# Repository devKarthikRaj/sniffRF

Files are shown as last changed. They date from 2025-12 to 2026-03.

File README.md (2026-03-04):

# sniffRF

## Project Snapshot
| Spec | Details |
|---|---|
| MCU | STM32L053R8 (M0+) |
| Firmware | Written in C++ via STM32CubeIDE |
| RF Detector | AD8318 Logarithmic (RF Power) Detector |
| Frequency Range | 902-928 MHz |
| Measurement Method | RF power -> Analog Voltage -> STM32 ADC |
| Power System | Li-ion battery with BQ24074 power path manager (charger included) |
| Display | OLED (SSD1306) |
| PCB | 4-layer mixed signal PCB designed in KiCad |
| Manufacturing | PCB fabrication and assembly done by JLCPCB |
| Cost | S$250 |
| Status | Hardware bring-up completed, core functionality validated (excluding OLED) |

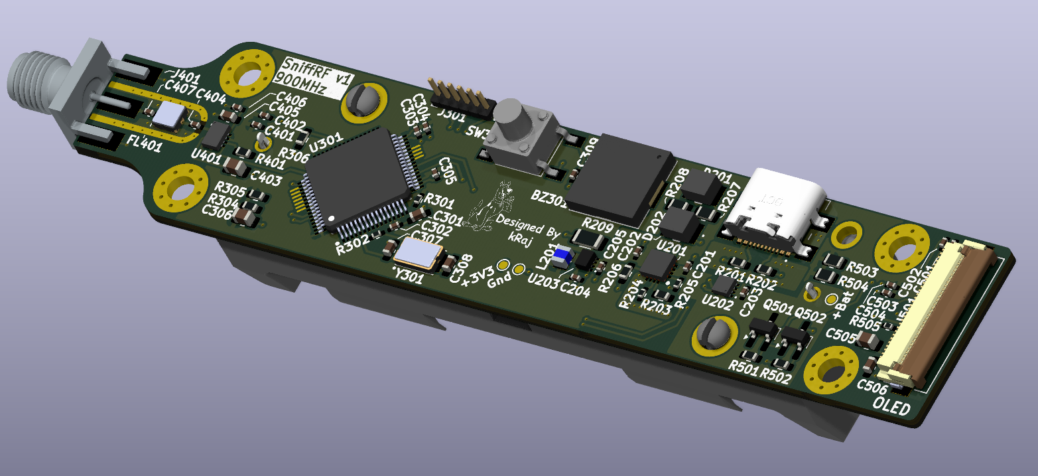
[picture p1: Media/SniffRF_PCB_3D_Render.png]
PCB 3D Render
 <br>
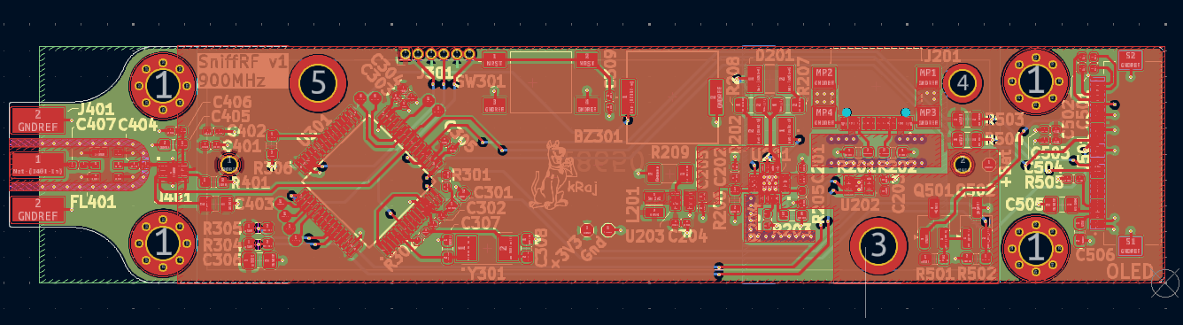
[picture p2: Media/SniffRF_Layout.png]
SniffRF Layout
 <br>
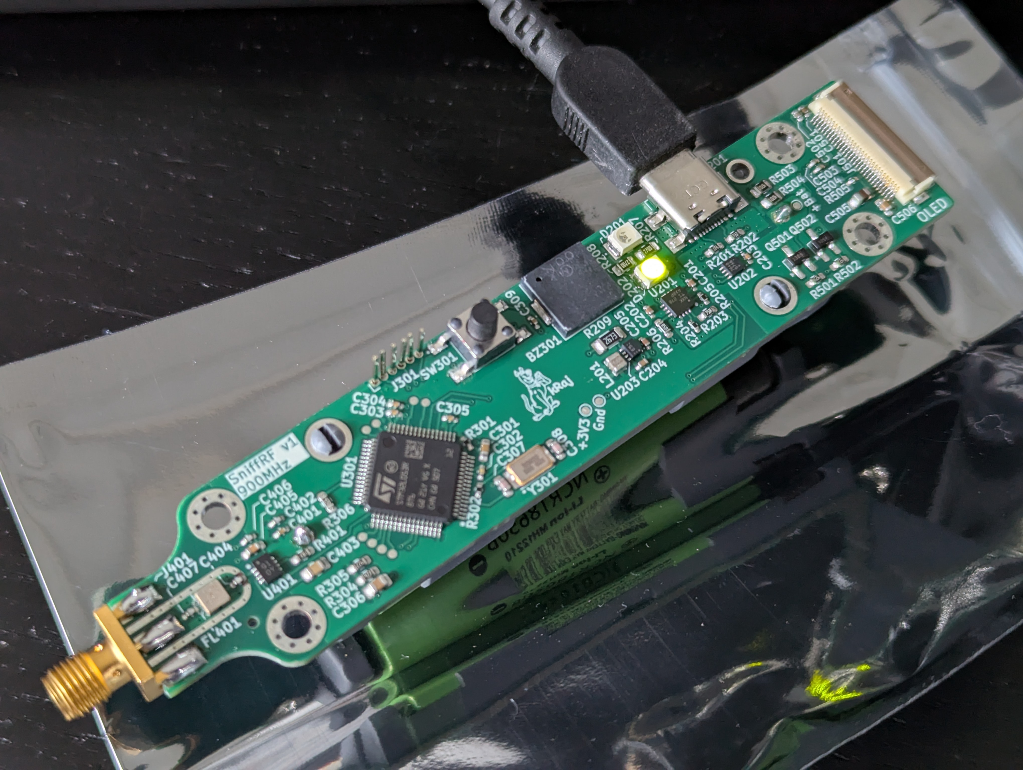
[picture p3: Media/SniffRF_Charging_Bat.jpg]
SniffRF Charging Battery
 <br>
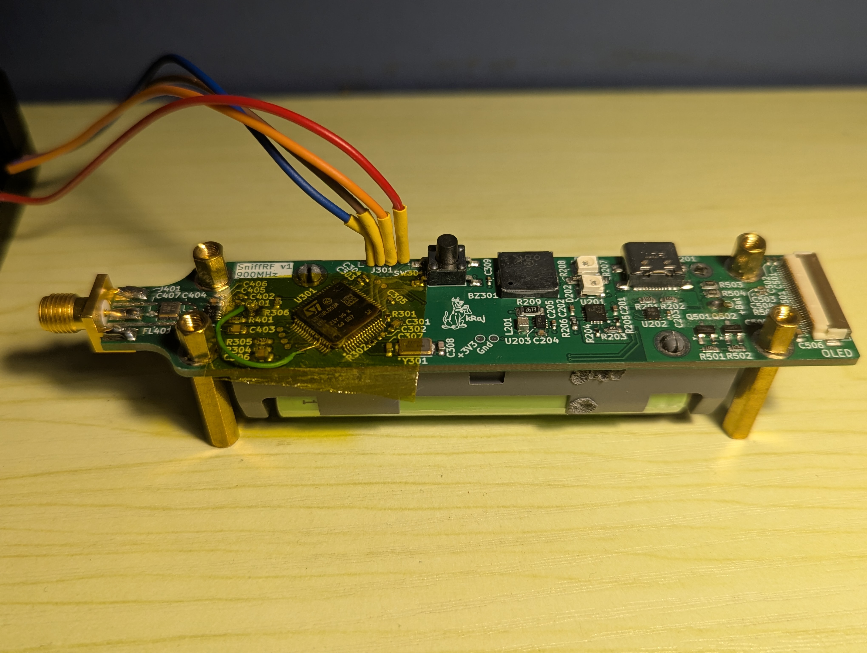
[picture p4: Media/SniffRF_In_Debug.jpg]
SniffRF In Debug
 <br>

## About
SniffRF is a simple RSSI detector aka a signal strength detector for the 902MHz to 928MHz band using an AD8318 logarithmic detector chip and built around an STM32L053R8 MCU. SniffRF displays the RSSI level on a mini OLED. SniffRF will also pulse a buzzer with varying frequency based on the RSSI level. <br>

## Sub-Systems
* RF: Input from SMA fed into AD8318 log detector. <br>
* MCU: STM32L053R8 M0+ interface circuitry, program/debug MCU via SWD.
* UI: OLED for visual feedback and buzzer for audio feedback.
* Power: 1x 18650 cell with BQ24074 power path manager, charge via USB-C, MAX1704 fuel gauge, simple buck converter for 3.3V

## Application
* SniffRF could be used to track RF transmitters using their radio signature. <br>
* SniffRF could also be used to gauge the noise floor at a particular location to select or deploy a receiver at said location. <br>   

*Note: As of now, SniffRF only tunes into the 902-928MHz band.*

## Bring-Up and Validation
* **STM32 MCU able to boot up and connect via J-Link debugger to STM32CubeIDE.** STM32 UART connection working as expected. <br>
* **AD8318 RSSI detection circuit is fully functional from about -60dBm to 0dBm. A known RF source (Sine wave transmitted at 915MHz from an Adalm Pluto SDR) was moved toward and away from the SniffRF PCB - this caused the RSSI readings to increase and decrease as expected.** <br>
* Li-Ion battery power path manager is able to charge the 18650 battery when a USB-C charge cable is plugged in. MAX1704 fuel gauge is able to read Li-Ion battery voltage + capacity and send this data over to the STM32 for display over UART. <br>
* Buzzer interfaced to STM32 is functional. <br>
* Unable to verify OLED functionality due to lack of assembled SniffRF boards, TBC... <br>

## Thoughts...
This is my first STM32 PCB! I made this PCB to learn STM32 design as well as try my hand at mixed signal PCB design. Feels good to finally strike this off my bucket list. Spent a few weekends working on this project over 3 months. More advanced RF PCBs to come!

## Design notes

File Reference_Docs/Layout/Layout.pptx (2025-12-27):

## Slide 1

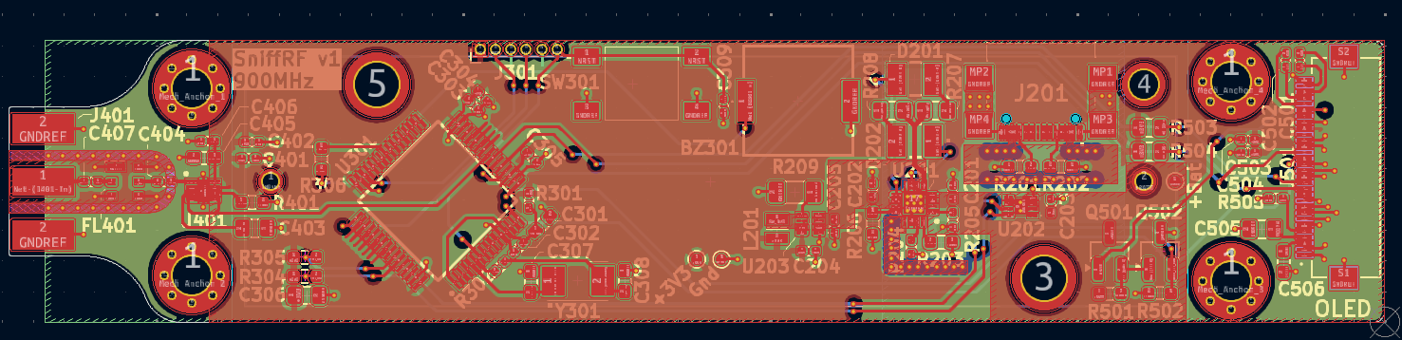
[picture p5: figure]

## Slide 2

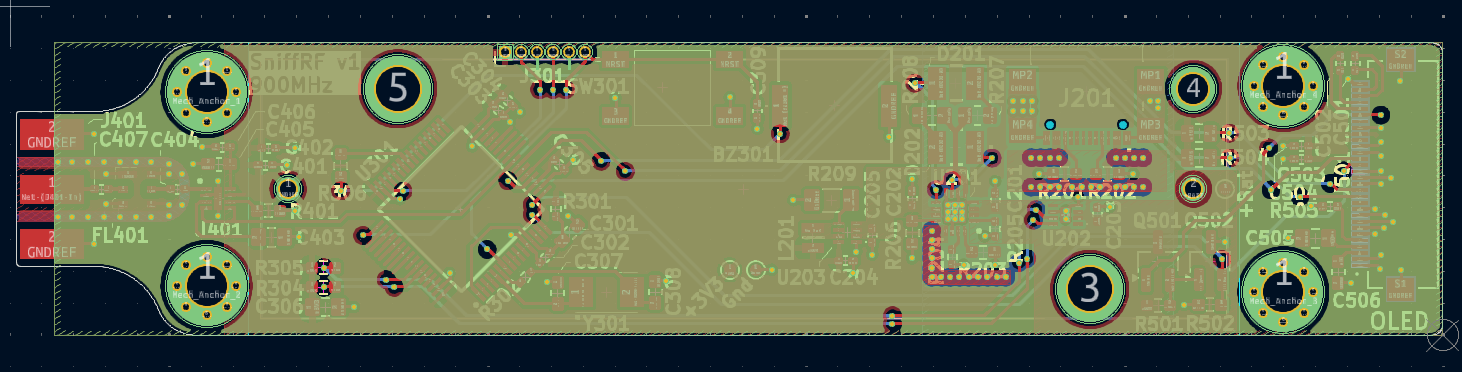
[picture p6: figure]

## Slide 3

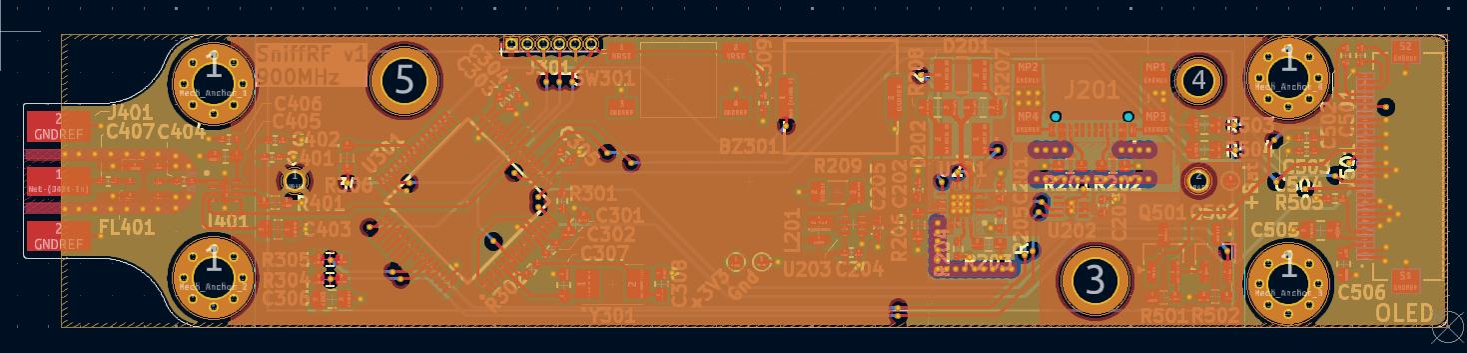
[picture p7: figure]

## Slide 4

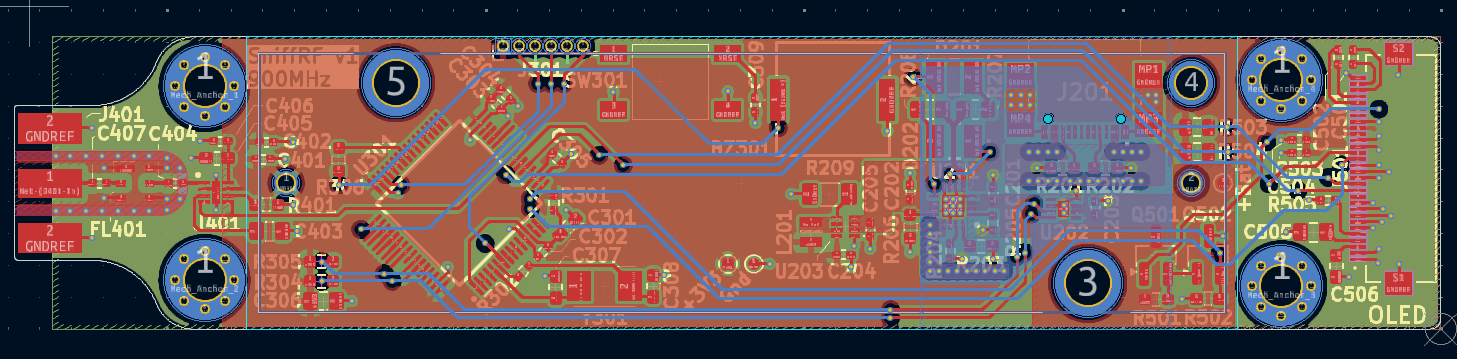
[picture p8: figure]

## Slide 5

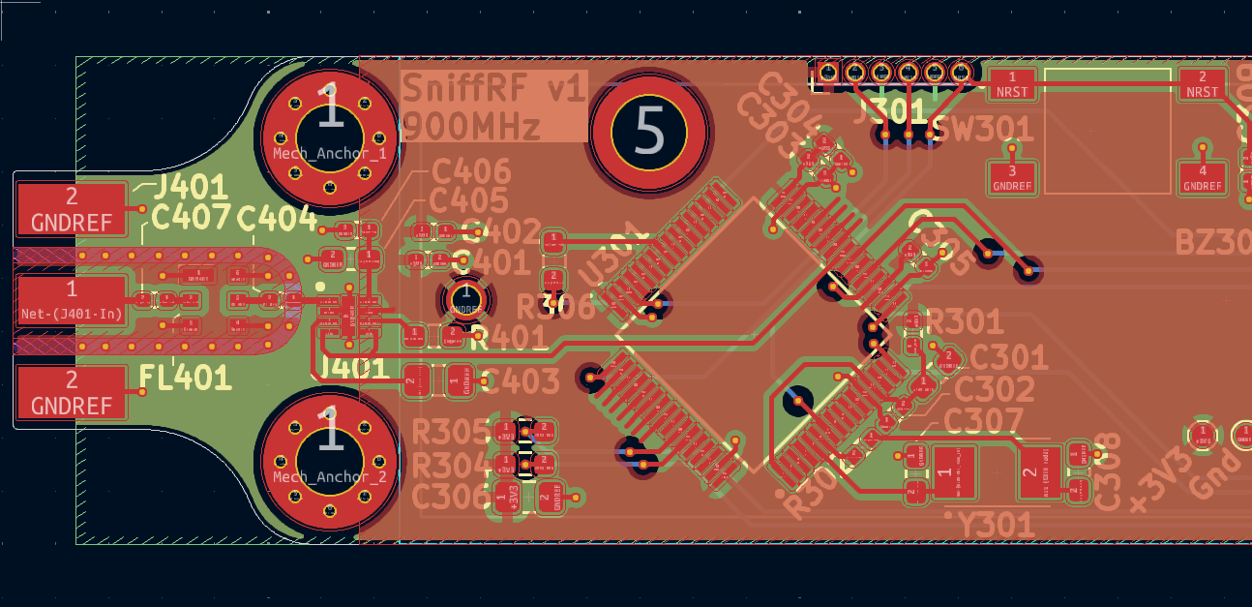
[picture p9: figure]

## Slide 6

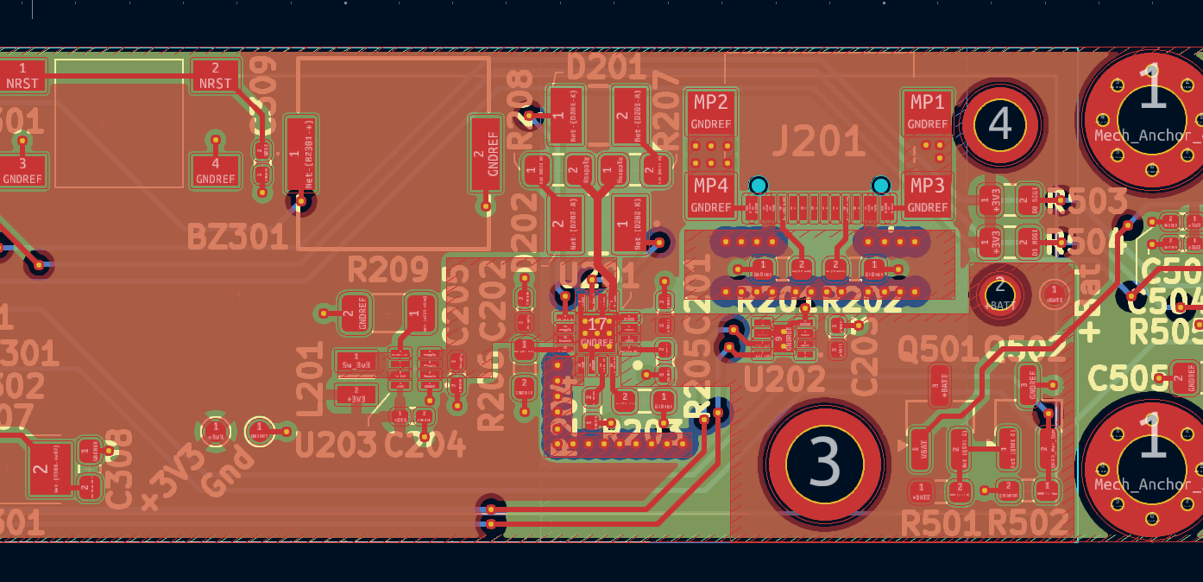
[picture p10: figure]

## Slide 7

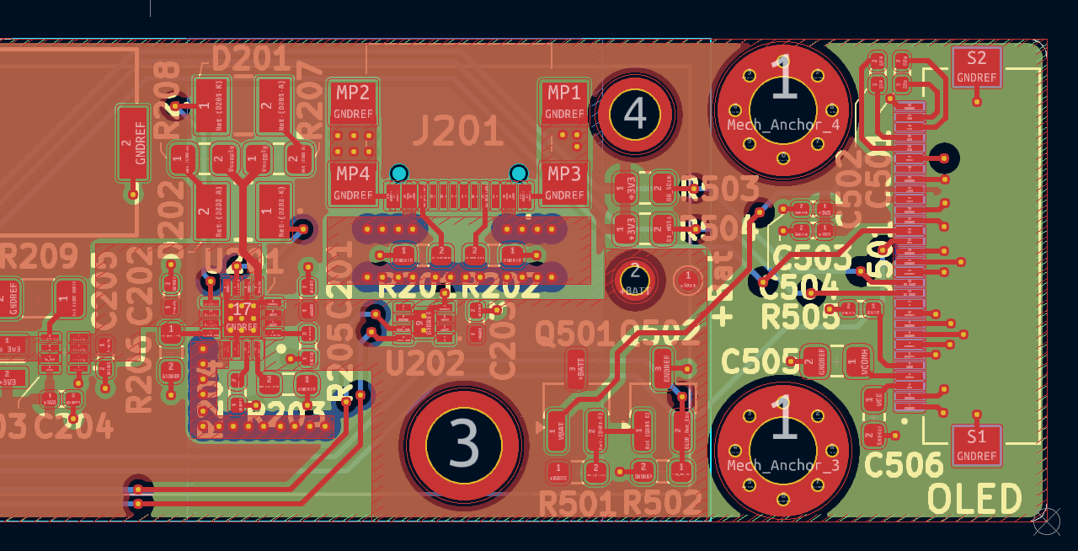
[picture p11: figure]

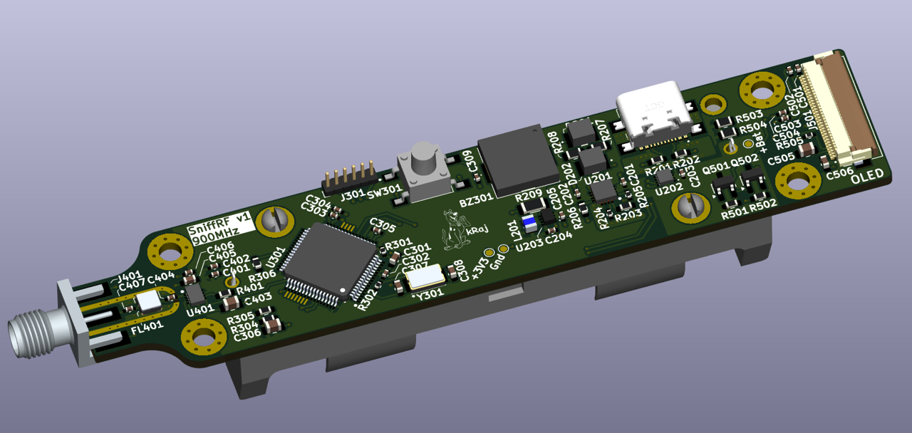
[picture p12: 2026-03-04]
Media/SniffRF_PCB_3D_Render_2.png

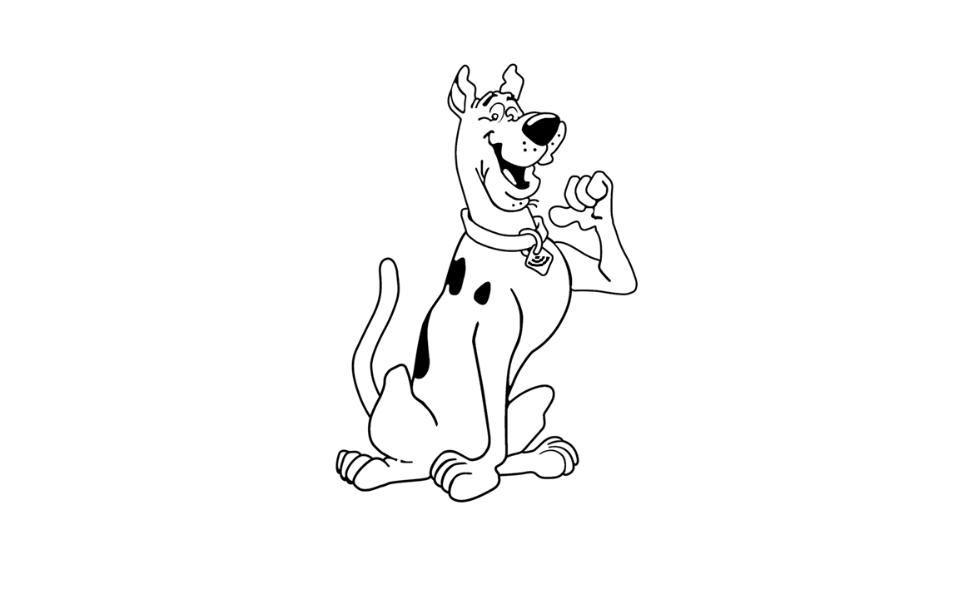
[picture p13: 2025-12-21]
sniffRF_PCB_Art.png

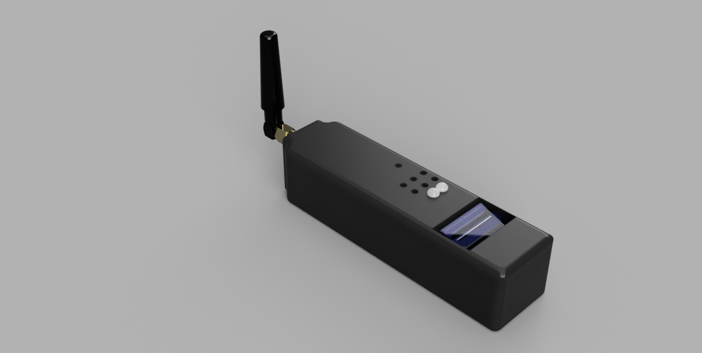
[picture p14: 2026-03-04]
CAD/SniffRF_Render.PNG

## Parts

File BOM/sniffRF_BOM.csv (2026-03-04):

Reference | Qty | Value | Manufacturer | MPN | Supplier | SPN | Alt Supplier | Alt SPN | LCSC PN | DNP
BT201 | 1 | 18650_Cell | Keystone | 1043P |  |  |  |  | C3029535
BZ301 | 1 | Buzzer | Murata | PKMCS0909E4000-R1 |  |  |  |  | C910763
C201,C202,C205 | 3 | 4.7uF | Samsung | CL05A475MP5NRNC |  |  |  |  | C23733
C203,C303,C304,C305,C309,C401 | 6 | 100nF | Samsung | CL05B104KO5NNNC |  |  |  |  | C1525
C204 | 1 | 10uF | Samsung | CL05A106MQ5NUNC |  |  |  |  | C15525
C301 | 1 | 1uF | Samsung | CL10A105KB8NNNC |  |  |  |  | C15849
C302 | 1 | 10nF | Samsung | CL05B103KB5NNNC |  |  |  |  | C15195
C306 | 1 | 4.7uF | Samsung | CL21A475KAQNNNE |  |  |  |  | C1779
C307,C308 | 2 | 20pF | Samsung | CL10C200JB8NNNC |  |  |  |  | C1648
C402,C406,C407 | 3 | 100pF | Yageo | CC0402JRNPO9BN101 |  |  |  |  | C106200
C403 | 1 | 10nF | Yageo | CC0805KRX7R9BB103 |  |  |  |  | C83170
C404 | 1 | 33pF | Yageo | CC0402JRNPO9BN330 |  |  |  |  | C107005
C405 | 1 | 47nF | Yageo | CC0603KRX7R9BB473 |  |  |  |  | C107093
C501,C502 | 2 | 1uF 16V X5R | Yageo | CC0402KRX5R7BB105 |  |  |  |  | C325464
C503,C504 | 2 | 1uF 16V | Yageo | CC0402KRX5R7BB105 |  |  |  |  | C325464
C505 | 1 | 4.7uF 16V X7R | Yageo | CC0805KKX7R7BB475 |  |  |  |  | C277499
C506 | 1 | 2.2uF 16V | Samsung | CL10A225KO8NNNC |  |  |  |  | C23630
D201 | 1 | LED Red | Dialight | 5973008207F |  |  |  |  | C6095189
D202 | 1 | LED Green | Dialight | 5973308207F |  |  |  |  | C7188877
FL401 | 1 | ~ | Qualcomm | B39921B3728U410 |  |  |  |  | C2650953
H101,H102,H103,H104 | 4 | MountingHole
J201 | 1 | USBC | Global Connector Technology | USB4110-GF-A |  |  |  |  | C5143397
J301 | 1 | SWD |  |  |  |  |  |  |  | DNP
J401 | 1 | Ant | Cinch Connectivity Solutions Johnson | 142-0701-801 | DigiKey | J502-ND |  |  |  | DNP
J501 | 1 | FFC_Hirose_FH12-30S-0.5SH_55_ | Hirose | FH12-30S-0.5SH(55) |  |  |  |  | C506793
L201 | 1 | 2.2uH | Murata | DFE201612E-2R2M=P2 |  |  |  |  | C337893
PA15,PB0,PB1,PB2,PC5,PC10,PC11,PC12 | 8 | TestPoint_Alt
Q501 | 1 | PMOS | OnSemi | FDN338P |  |  |  |  | C24855
Q502 | 1 | NMOS | OnSemi | FDN335N |  |  |  |  | C241804
R201,R202 | 2 | 5.1kΩ | UNI-ROYAL | 0603WAF5101T5E |  |  |  |  | C23186
R203 | 1 | 590Ω | Yageo | AC0603FR-07590RL |  |  |  |  | C227973
R204 | 1 | 2.94kΩ | Yageo | RT0402BRD072K94L |  |  |  |  | C852709
R205 | 1 | 10kΩ | UNI-ROYAL | 0402WGJ0103TCE |  |  |  |  | C25531
R206 | 1 | 1.1kΩ | Yageo | RT0603BRE071K1L |  |  |  |  | C705821
R207,R208 | 2 | 270Ω | UNI-ROYAL | 0805W8F2700T5E |  |  |  |  | C17590
R209 | 1 | 267kΩ | Yageo | RT1206BRD07267KL |  |  |  |  | C870591
R301 | 1 | 0Ω | UNI-ROYAL | 0402WGF0000TCE |  |  |  |  | C17168
R302 | 1 | 390Ω | Yageo | RC0402FR-07390RL |  |  |  |  | C137997
R304,R305 | 2 | 4.7kΩ | UNI-ROYAL | 0603WAF4701T5E |  |  |  |  | C23162
R306 | 1 | 47Ω | UNI-ROYAL | 0603WAF470JT5E |  |  |  |  | C23182
R401 | 1 | 18kΩ | UNI-ROYAL | 0603WAF1802T5E |  |  |  |  | C25810
R501,R502 | 2 | 47kΩ | UNI-ROYAL | 0603WAF4702T5E |  |  |  |  | C25819
R503,R504 | 2 | 4.7kΩ | UNI-ROYAL | 0805W8F4701T5E |  |  |  |  | C17673
R505 | 1 | 620kΩ | Yageo | RC0402FR-07620KL |  |  |  |  | C137952
SW301 | 1 | Reset | TE Connectivity | FSM6JSMA |  |  |  |  | C178262
TP201,TP202,TP203 | 3 | +Batt
U201 | 1 | BQ24074RGTRG4 | Texas Instruments | BQ24074RGTR |  |  |  |  | C54313
U202 | 1 | MAX17048G+T10 | Analog Devices | MAX17048G+T10 |  |  |  |  | C2682616
U203 | 1 | TPS62840DLCR | Texas Instruments | TPS62840DLCR |  |  |  |  | C2071859
U301 | 1 | STM32L053R8T6 | ST Microelectronics | STM32L053R8T6 |  |  |  |  | C79207
U401 | 1 | AD8317ACPZ-R7 | Analog Devices | AD8317ACPZ-R7 |  |  |  |  | C578693
Y301 | 1 | Crystal | ECS | ECS-80-12-30Q-DS-TR |  |  |  |  | C2450805

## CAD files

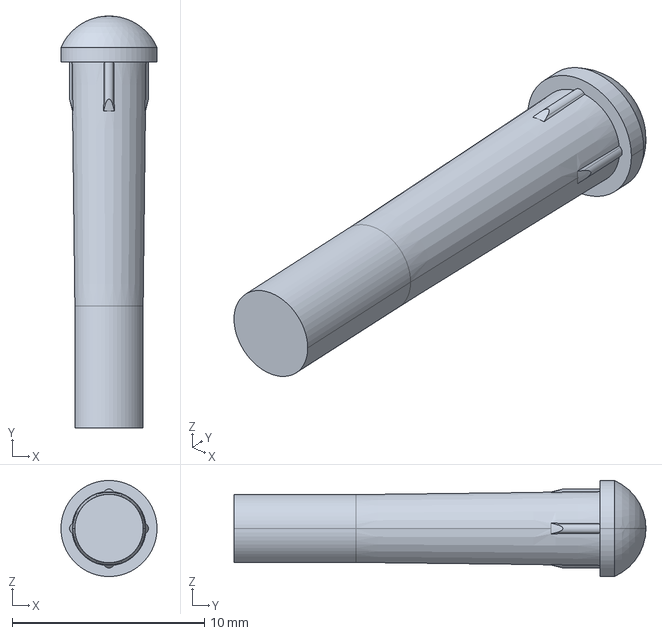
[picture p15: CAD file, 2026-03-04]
CAD/Peripherals/lightpipe.stp
5.00 x 21.5 x 5.00 mm

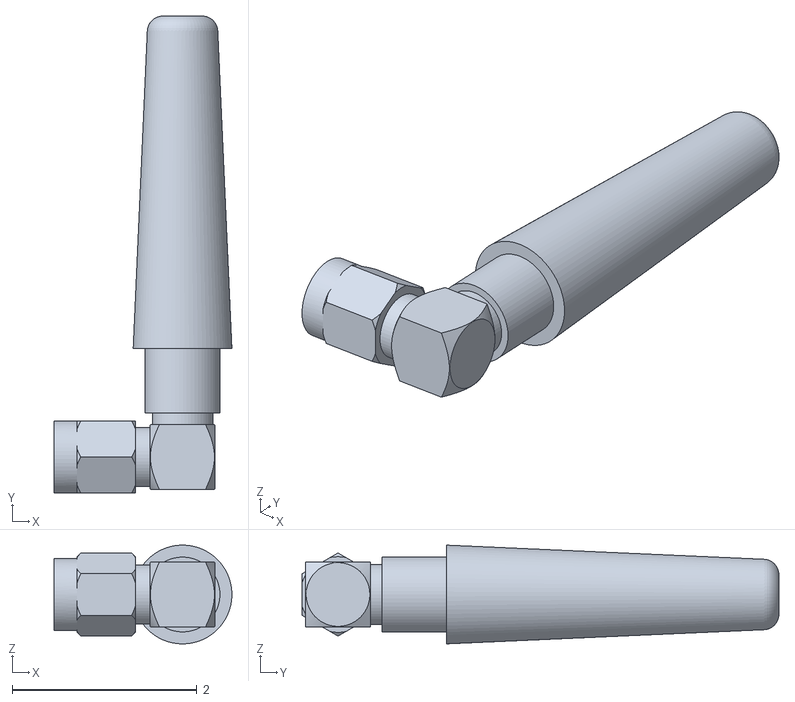
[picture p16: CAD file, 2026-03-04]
CAD/Peripherals/antenna_900mhz.stl
1.93 x 5.17 x 1.07

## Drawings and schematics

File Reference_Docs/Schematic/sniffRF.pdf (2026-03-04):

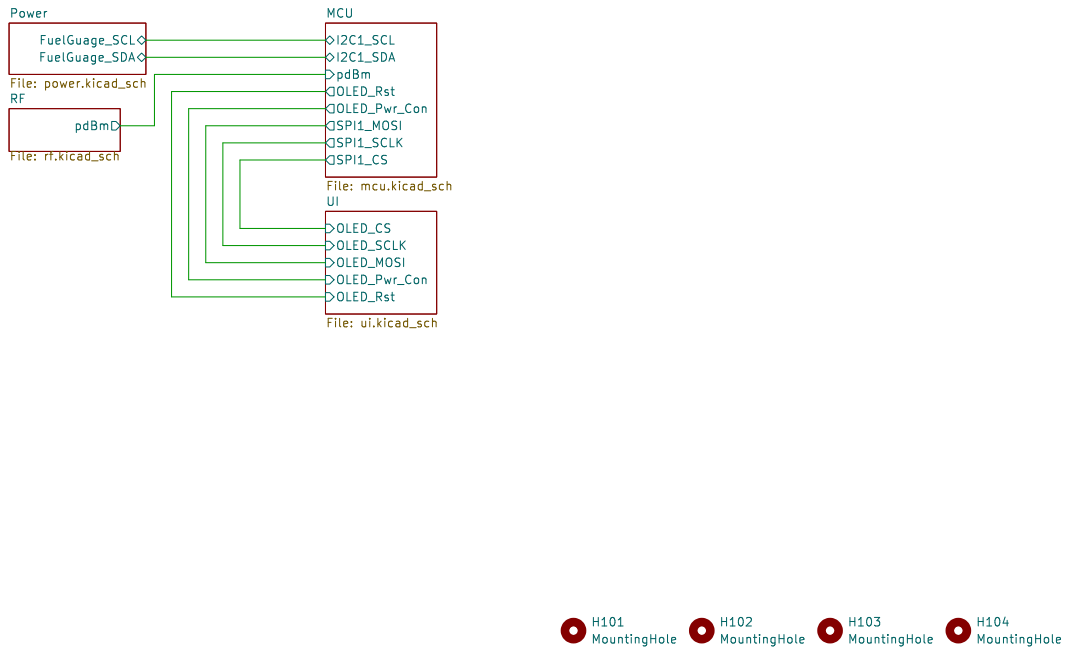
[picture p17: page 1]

File: mcu.kicad_sch OLED_CS OLED_MOSI OLED_Pwr_Con OLED_SCLK OLED_Rst UI File: ui.kicad_sch

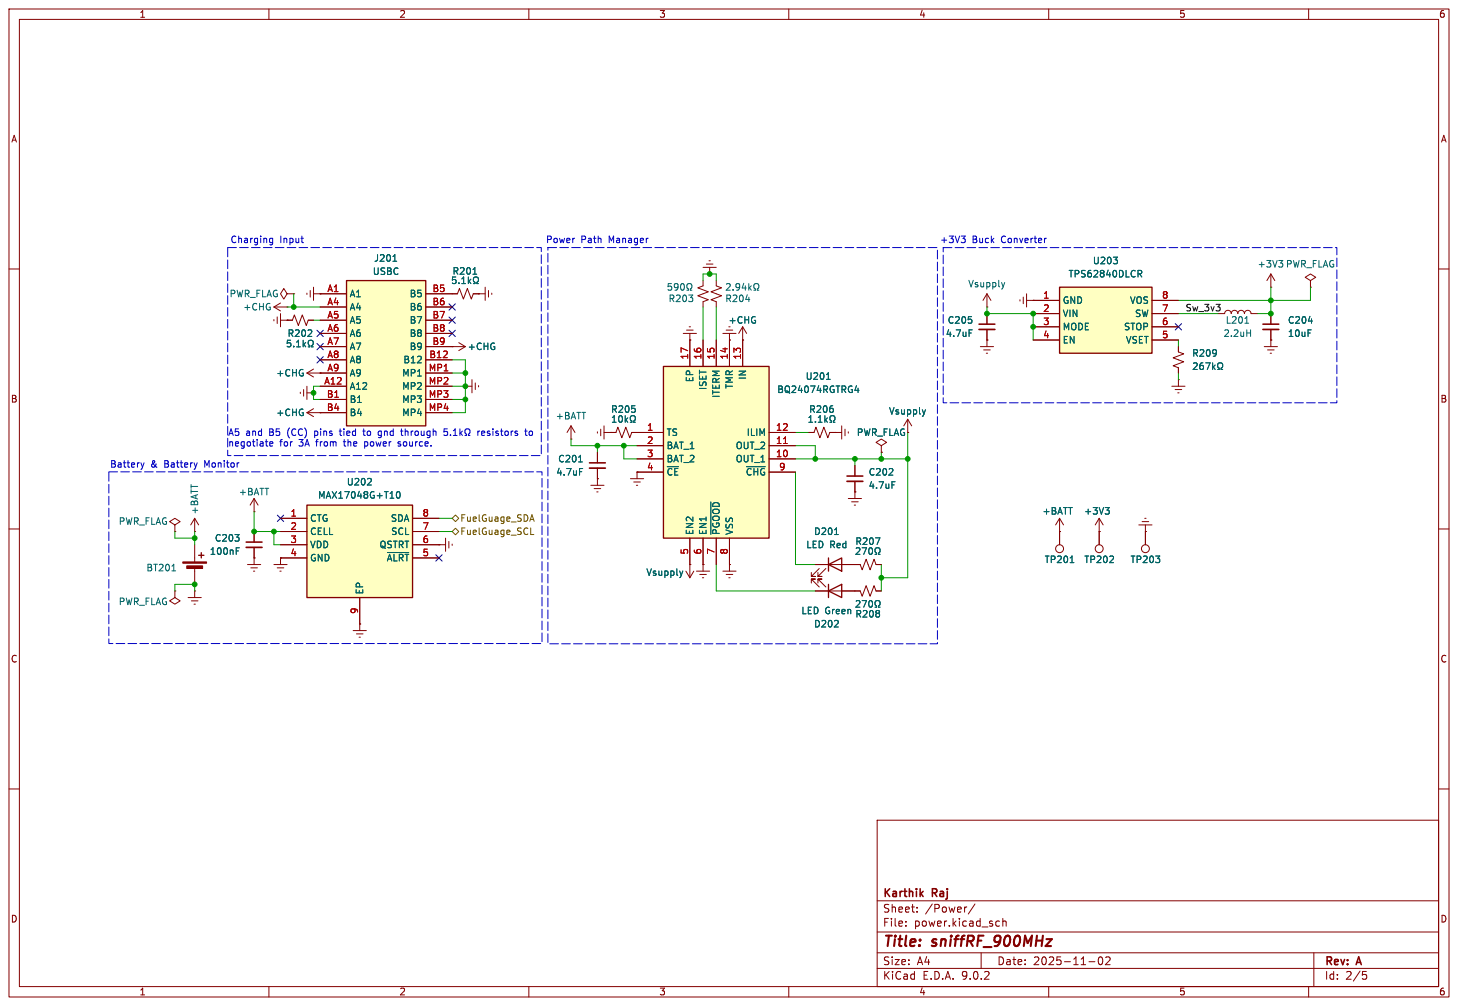
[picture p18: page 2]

6 ITERM 15 ~{PGOOD} 7 TMR 14 VSS

9 SDA 8 SCL 7 QSTRT 6 ~{ALRT}5 U202 MAX17048G+T10 +3V3 C202

9 SDA 8 SCL 7 QSTRT 6 ~{ALRT}5 C203

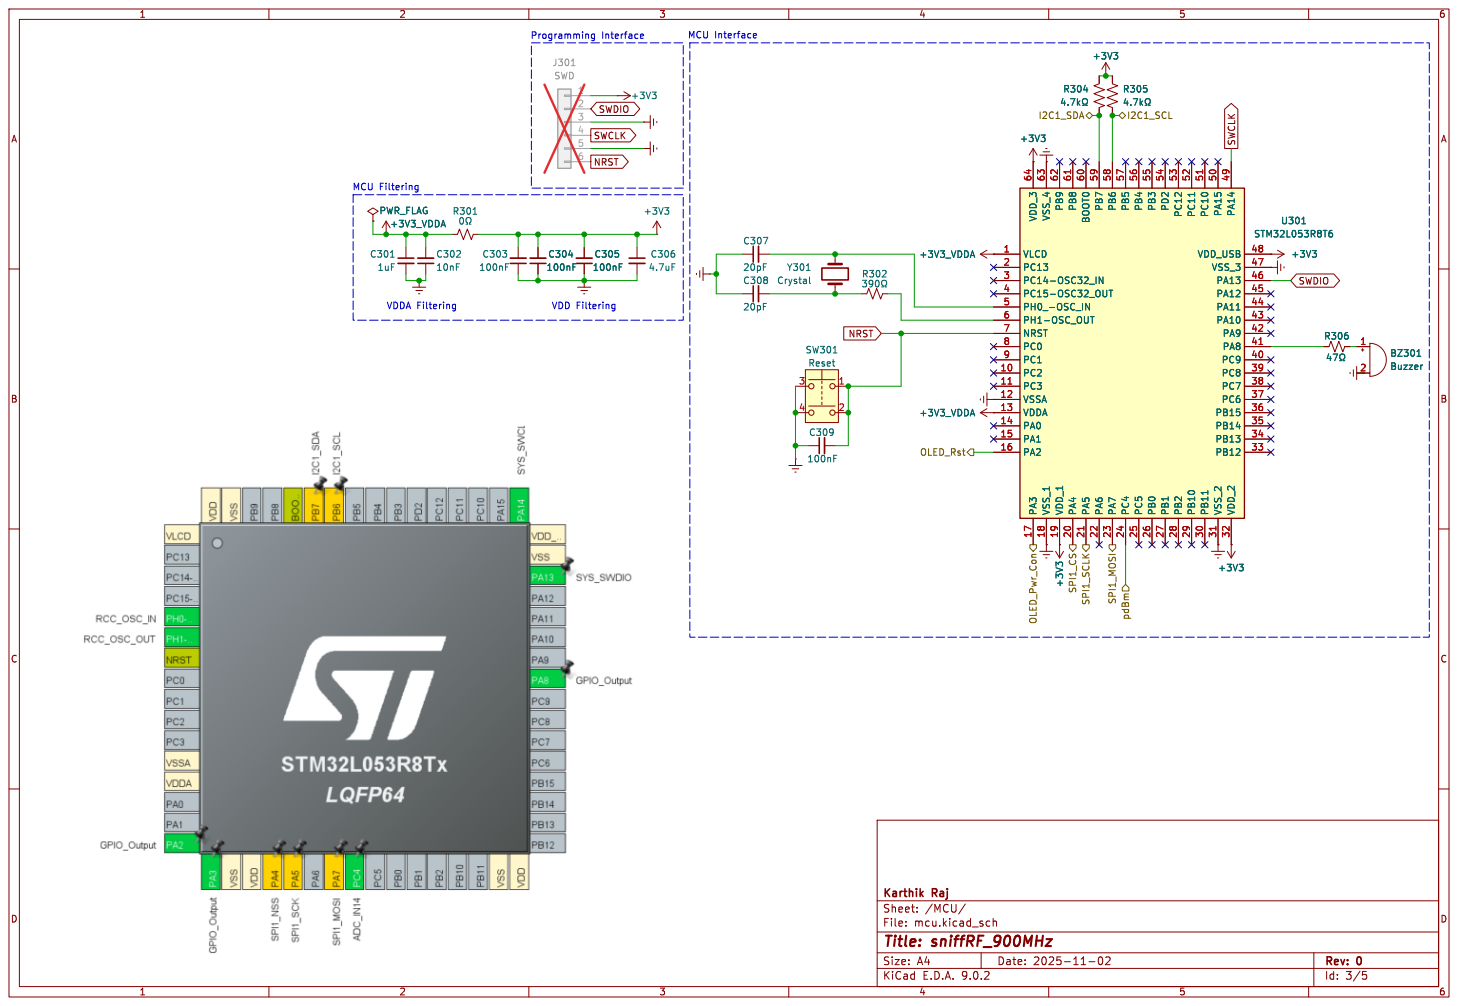
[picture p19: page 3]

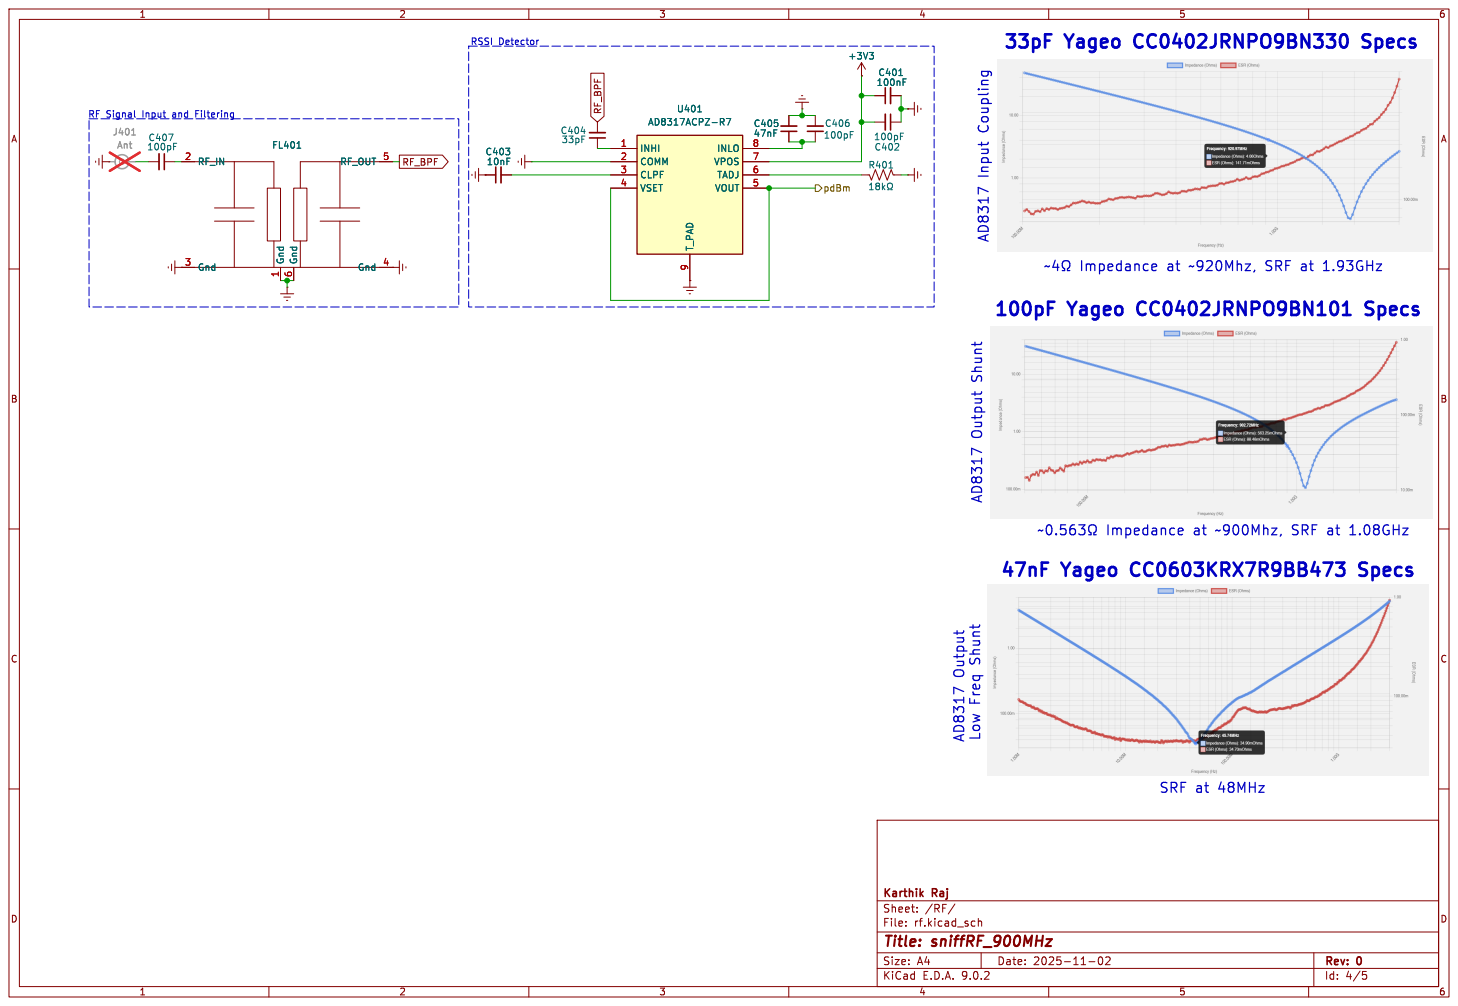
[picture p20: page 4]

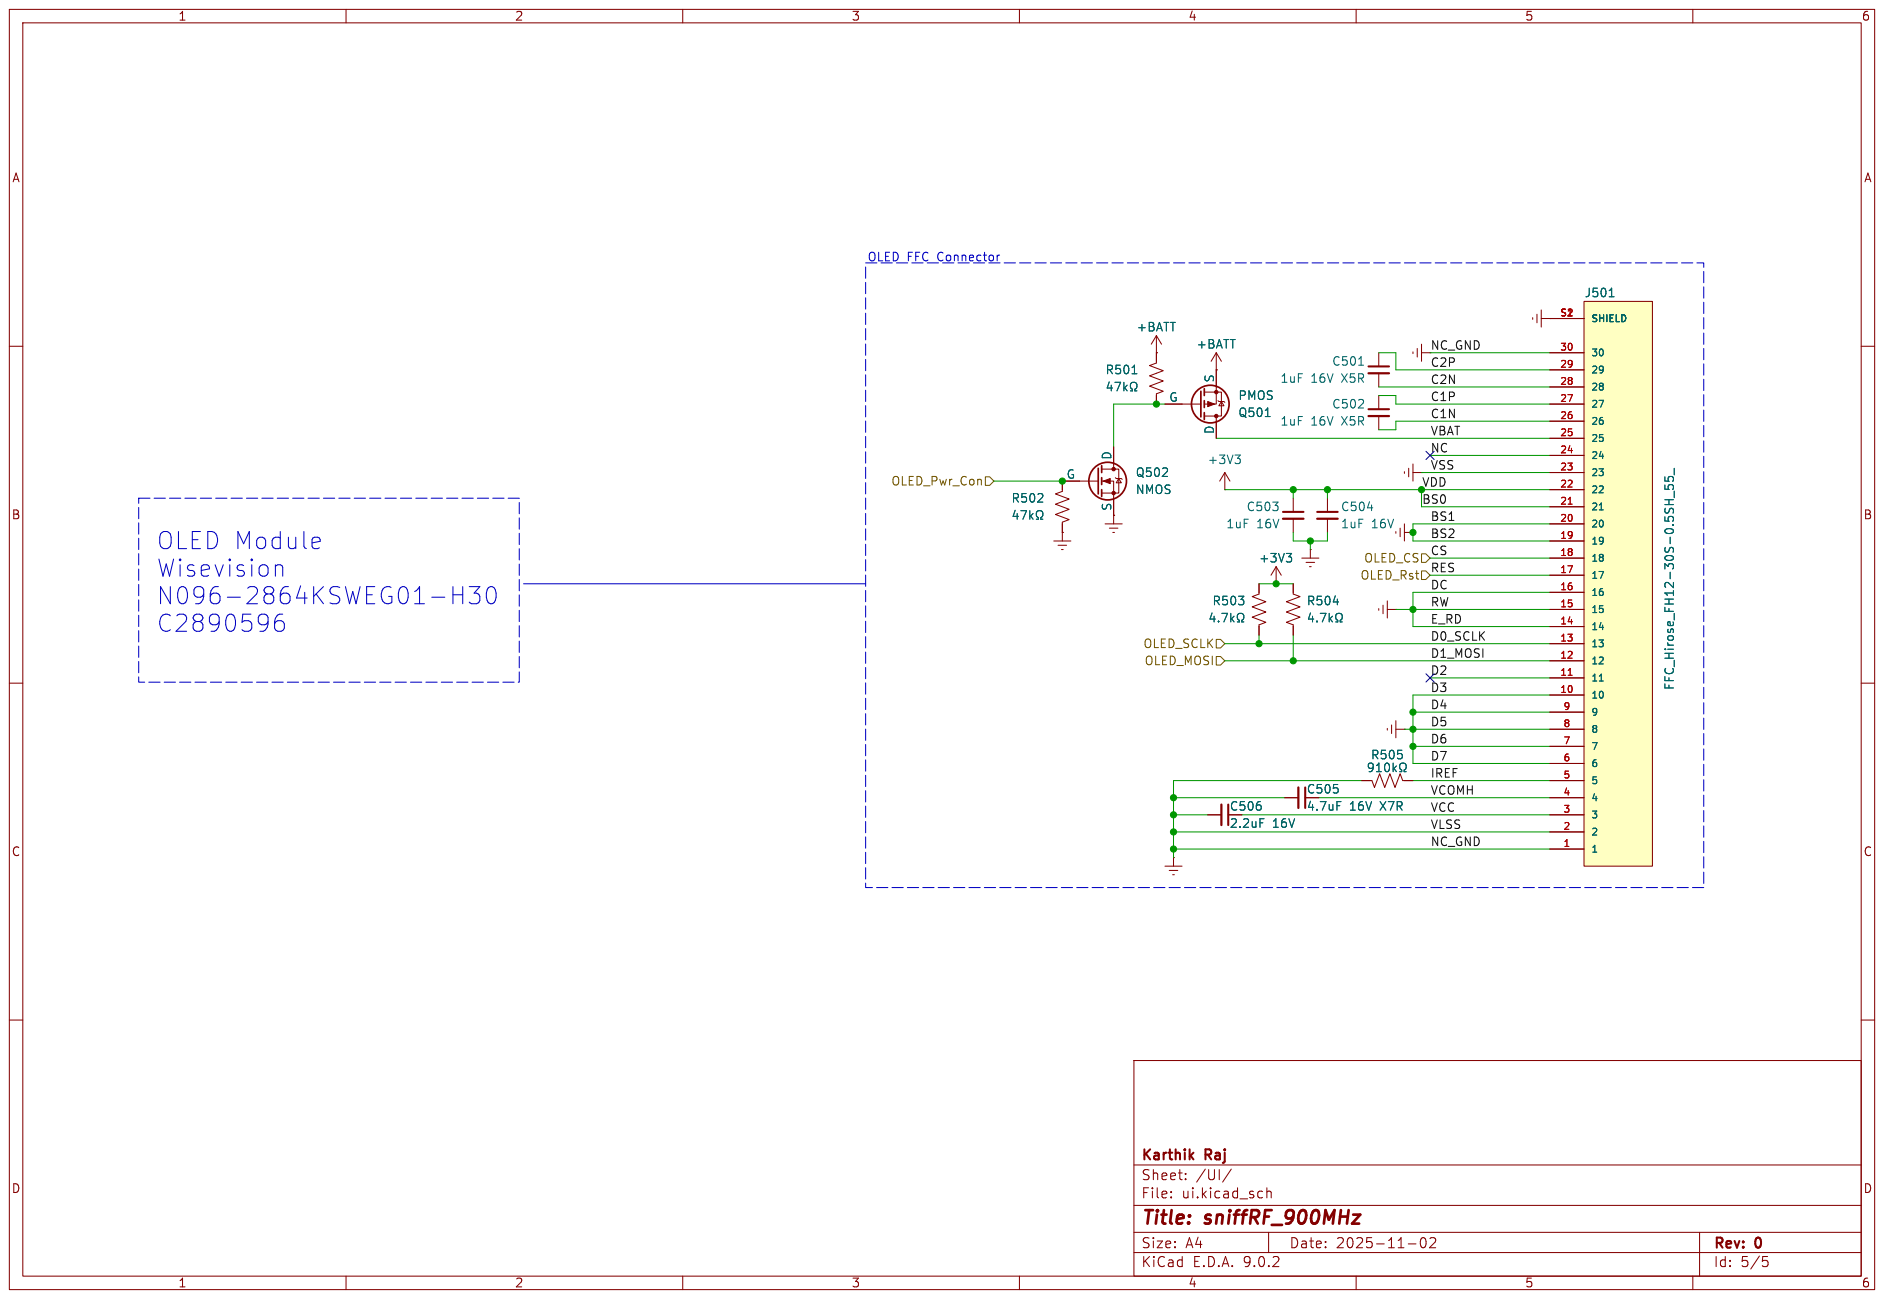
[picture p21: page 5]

D3 OLED FFC Connector OLED Module

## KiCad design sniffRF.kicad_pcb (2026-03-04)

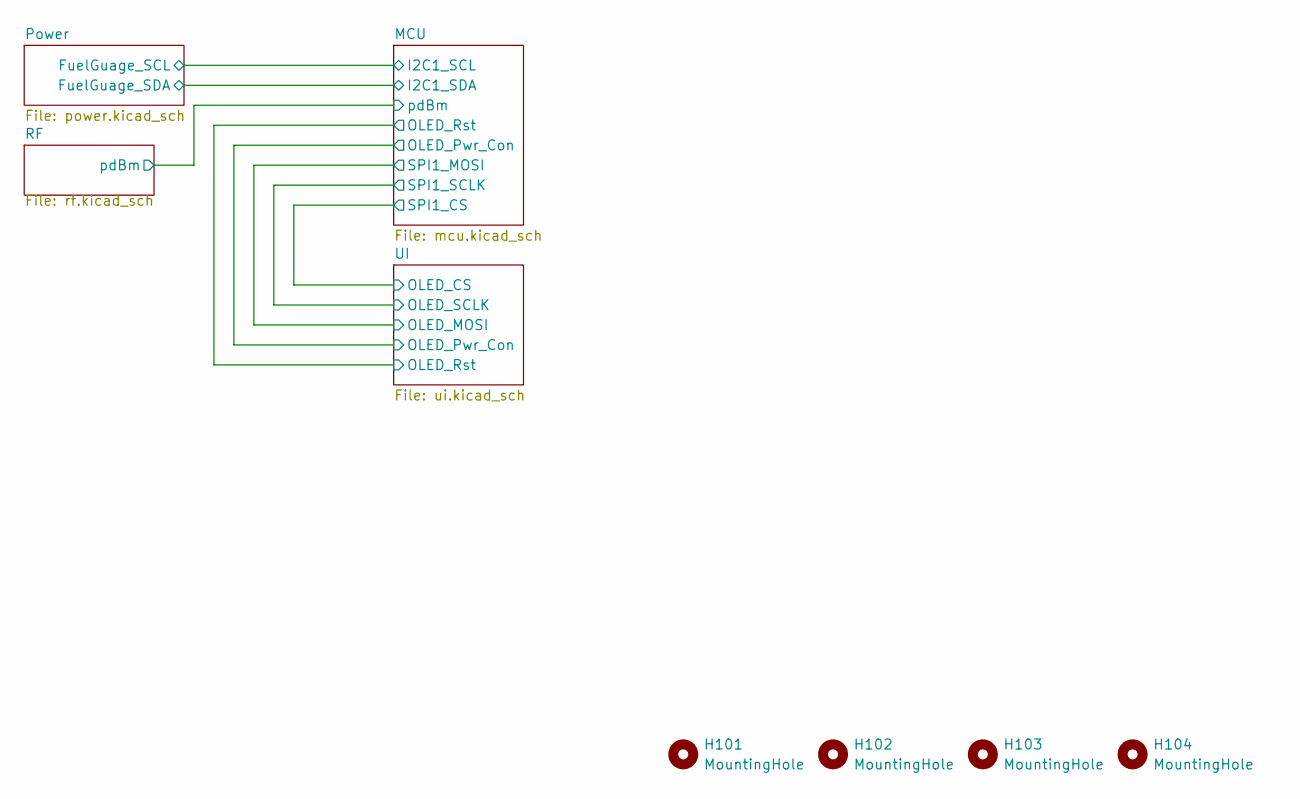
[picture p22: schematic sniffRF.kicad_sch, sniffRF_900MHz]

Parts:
H101, H102, H103, H104: MountingHole; MountingHole_PC104_Reinforced

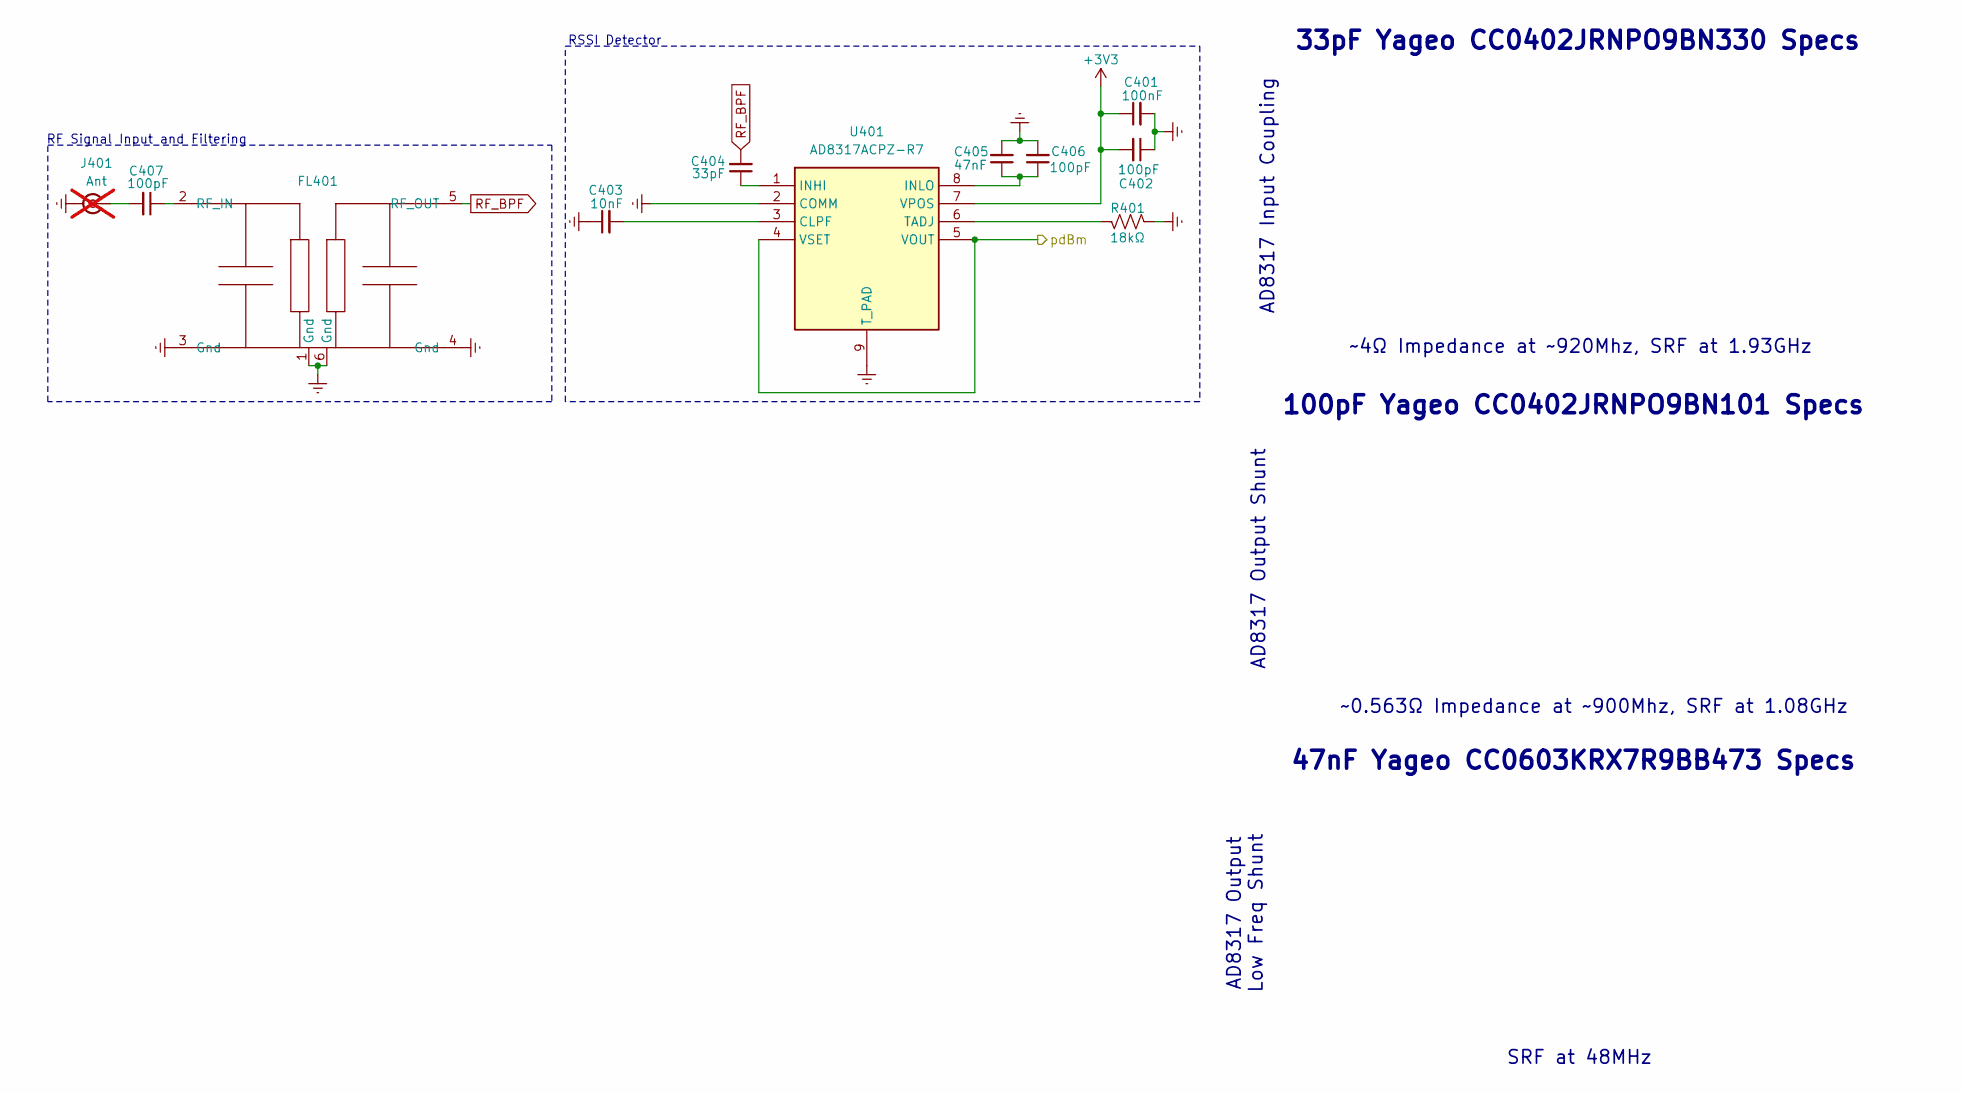
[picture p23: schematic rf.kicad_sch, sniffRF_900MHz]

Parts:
C401: 100nF; C_0402_1005Metric_Pad0.74x0.62mm_HandSolder; MPN CL05B104KO5NNNC; LCSC PN C1525
C402, C406, C407: 100pF; C_0402_1005Metric_Pad0.74x0.62mm_HandSolder; MPN CC0402JRNPO9BN101; LCSC PN C106200
C403: 10nF; C_0805_2012Metric_Pad1.18x1.45mm_HandSolder; MPN CC0805KRX7R9BB103; LCSC PN C83170
C404: 33pF; C_0402_1005Metric_Pad0.74x0.62mm_HandSolder; MPN CC0402JRNPO9BN330; LCSC PN C107005
C405: 47nF; C_0603_1608Metric_Pad1.08x0.95mm_HandSolder; MPN CC0603KRX7R9BB473; LCSC PN C107093
FL401: BPF_Qualcomm_B39921B3728U410; MPN B39921B3728U410; LCSC PN C2650953
J401: Ant; SMA_Cinch_142-0701-851; MPN 142-0701-801; not fitted
R401: 18kΩ; R_0603_1608Metric_Pad0.98x0.95mm_HandSolder; MPN 0603WAF1802T5E; LCSC PN C25810
U401: AD8317ACPZ-R7; RssiDet_AnalogDevices_SON50P200X300X80-9N-D; Manufacturer_Part_Number AD8317ACPZ-R7; Mouser Part Number 584-AD8317ACPZ-R7

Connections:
+3V3: C401.1, C402.2, U401.7 (VPOS); also elsewhere on the board
/MCU/pdBm: U401.4 (VSET), U401.5 (VOUT); also elsewhere on the board
GNDREF: C401.2, C402.1, C403.1, C405.2, C406.2, FL401.1 (Gnd), FL401.3 (Gnd), FL401.4 (Gnd), FL401.6 (Gnd), J401.2 (Ext), R401.2, U401.2 (COMM), U401.9 (T_PAD); also elsewhere on the board
unnamed: C407.1, FL401.2 (RF_IN)
unnamed: C407.2, J401.1 (In)
unnamed: C403.2, U401.3 (CLPF)
unnamed: C404.1, U401.1 (INHI)
unnamed: C405.1, C406.1, U401.8 (INLO)
unnamed: R401.1, U401.6 (TADJ)
RF_BPF: C404.2, FL401.5 (RF_OUT)

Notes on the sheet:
AD8317 Output Shunt
33pF Yageo CC0402JRNPO9BN330 Specs
47nF Yageo CC0603KRX7R9BB473 Specs
100pF Yageo CC0402JRNPO9BN101 Specs
~4Ω Impedance at ~920Mhz, SRF at 1.93GHz
AD8317 Output Low Freq Shunt
RF Signal Input and Filtering
~0.563Ω Impedance at ~900Mhz, SRF at 1.08GHz
SRF at 48MHz
AD8317 Input Coupling
RSSI Detector

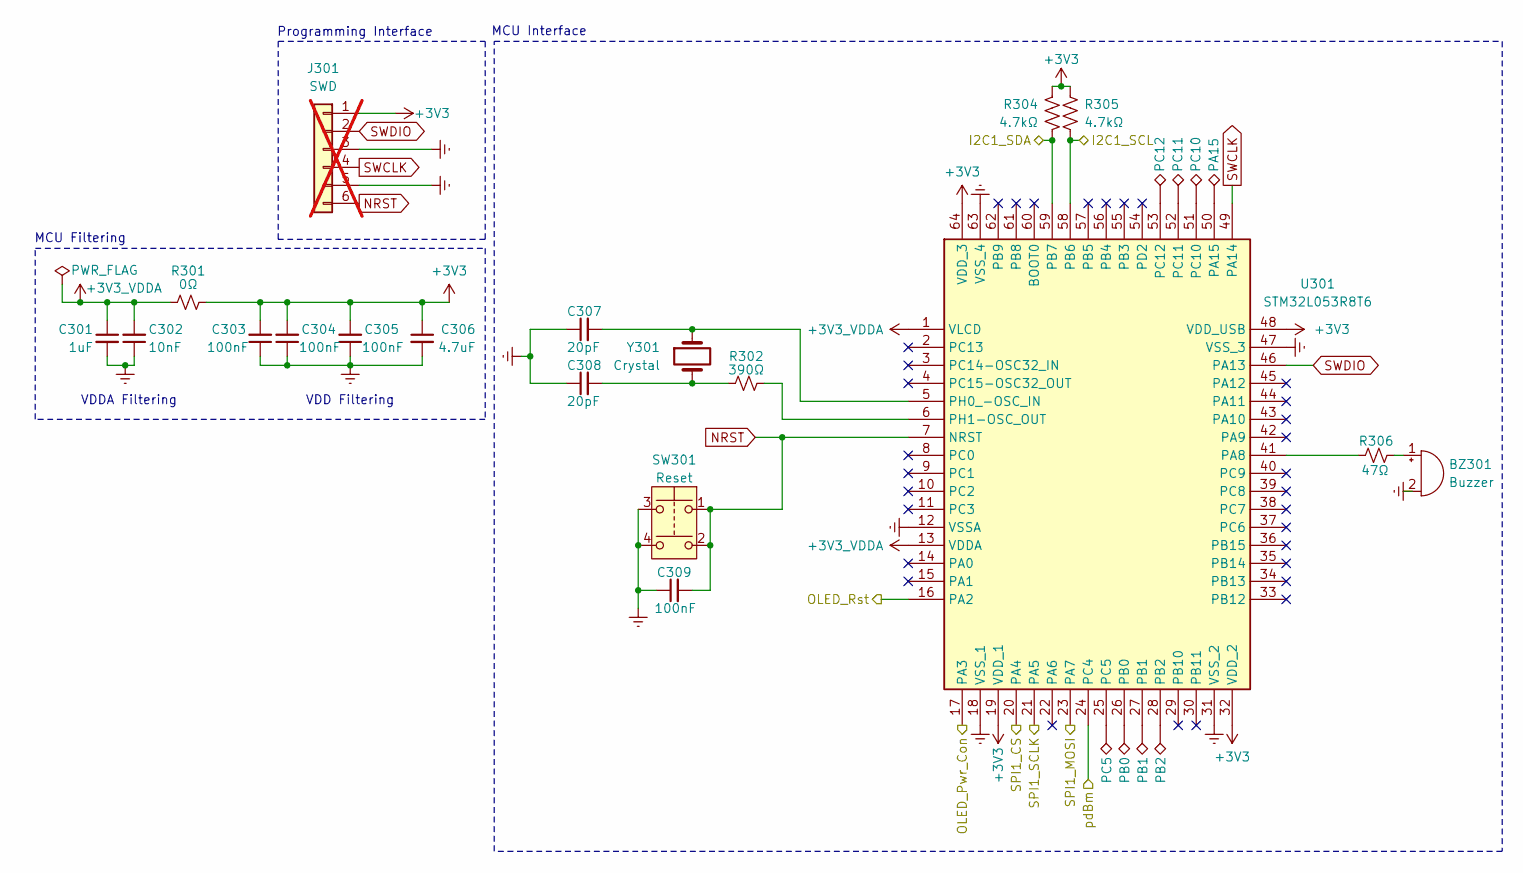
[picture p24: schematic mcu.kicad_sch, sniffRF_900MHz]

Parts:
BZ301: Buzzer; Buzzer_Murata_PKMCS0909E4000R1; MPN PKMCS0909E4000-R1; LCSC PN C910763
C301: 1uF; C_0603_1608Metric_Pad1.08x0.95mm_HandSolder; MPN CL10A105KB8NNNC; LCSC PN C15849
C302: 10nF; C_0402_1005Metric_Pad0.74x0.62mm_HandSolder; MPN CL05B103KB5NNNC; LCSC PN C15195
C303, C304, C305, C309: 100nF; C_0402_1005Metric_Pad0.74x0.62mm_HandSolder; MPN CL05B104KO5NNNC; LCSC PN C1525
C306: 4.7uF; C_0805_2012Metric_Pad1.18x1.45mm_HandSolder; MPN CL21A475KAQNNNE; LCSC PN C1779
C307, C308: 20pF; C_0603_1608Metric_Pad1.08x0.95mm_HandSolder; MPN CL10C200JB8NNNC; LCSC PN C1648
J301: SWD; PinHeader_1x06_P1.27mm_Vertical; not fitted
PA15: TestPoint_Alt; TestPoint_Pad_D1.0mm
PB0, PB1, PB2: TestPoint_Alt; TestPoint_Pad_D1.0mm
PC5, PC10, PC11, PC12: TestPoint_Alt; TestPoint_Pad_D1.0mm
R301: 0Ω; R_0402_1005Metric_Pad0.72x0.64mm_HandSolder; MPN 0402WGF0000TCE; LCSC PN C17168
R302: 390Ω; R_0402_1005Metric_Pad0.72x0.64mm_HandSolder; MPN RC0402FR-07390RL; LCSC PN C137997
R304, R305: 4.7kΩ; R_0603_1608Metric_Pad0.98x0.95mm_HandSolder; MPN 0603WAF4701T5E; LCSC PN C23162
R306: 47Ω; R_0603_1608Metric_Pad0.98x0.95mm_HandSolder; MPN 0603WAF470JT5E; LCSC PN C23182
SW301: Reset; Button_TE_FSM6JSMATR; MPN FSM6JSMA; LCSC PN C178262
U301: STM32L053R8T6; MCU_STM_QFP50P1200X1200X160-64N; MPN STM32L053R8T6; LCSC PN C79207
Y301: Crystal; Crystal_ECS_ECS801230QDSTR; MPN ECS-80-12-30Q-DS-TR; LCSC PN C2450805

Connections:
+3V3: C303.2, C304.2, C305.2, C306.1, J301.1, R301.2, R304.1, R305.1, U301.19 (VDD_1), U301.32 (VDD_2), U301.48 (VDD_USB), U301.64 (VDD_3); also elsewhere on the board
+3V3_VDDA: C301.1, C302.2, R301.1, U301.1 (VLCD), U301.13 (VDDA)
/MCU/I2C1_SCL: R305.2, U301.58 (PB6); also elsewhere on the board
/MCU/I2C1_SDA: R304.2, U301.59 (PB7); also elsewhere on the board
/MCU/OLED_Pwr_Con: U301.17 (PA3); also elsewhere on the board
/MCU/pdBm: U301.24 (PC4); also elsewhere on the board
/UI/CS: U301.20 (PA4); also elsewhere on the board
/UI/D0_SCLK: U301.21 (PA5); also elsewhere on the board
/UI/D1_MOSI: U301.23 (PA7); also elsewhere on the board
/UI/RES: U301.16 (PA2); also elsewhere on the board
GNDREF: BZ301.2 (-), C301.2, C302.1, C303.1, C304.1, C305.1, C306.2, C307.1, C308.1, C309.1, J301.3, J301.5, SW301.3, SW301.4, U301.12 (VSSA), U301.18 (VSS_1), U301.31 (VSS_2), U301.47 (VSS_3), U301.63 (VSS_4); also elsewhere on the board
NRST: C309.2, J301.6, SW301.1, SW301.2, U301.7 (NRST)
unnamed: BZ301.1 (+), R306.2
unnamed: C308.2, R302.1, Y301.2
unnamed: R306.1, U301.41 (PA8)
unnamed: PA15.1, U301.50 (PA15)
unnamed: PB0.1, U301.26 (PB0)
unnamed: PB1.1, U301.27 (PB1)
unnamed: PB2.1, U301.28 (PB2)
unnamed: PC5.1, U301.25 (PC5)
unnamed: PC10.1, U301.51 (PC10)
unnamed: PC11.1, U301.52 (PC11)
unnamed: PC12.1, U301.53 (PC12)
unnamed: C307.2, U301.5 (PH0_-OSC_IN), Y301.1
unnamed: R302.2, U301.6 (PH1-OSC_OUT)
SWCLK: J301.4, U301.49 (PA14)
SWDIO: J301.2, U301.46 (PA13)

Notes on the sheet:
VDD Filtering
MCU Interface
MCU Filtering
Programming Interface
VDDA Filtering

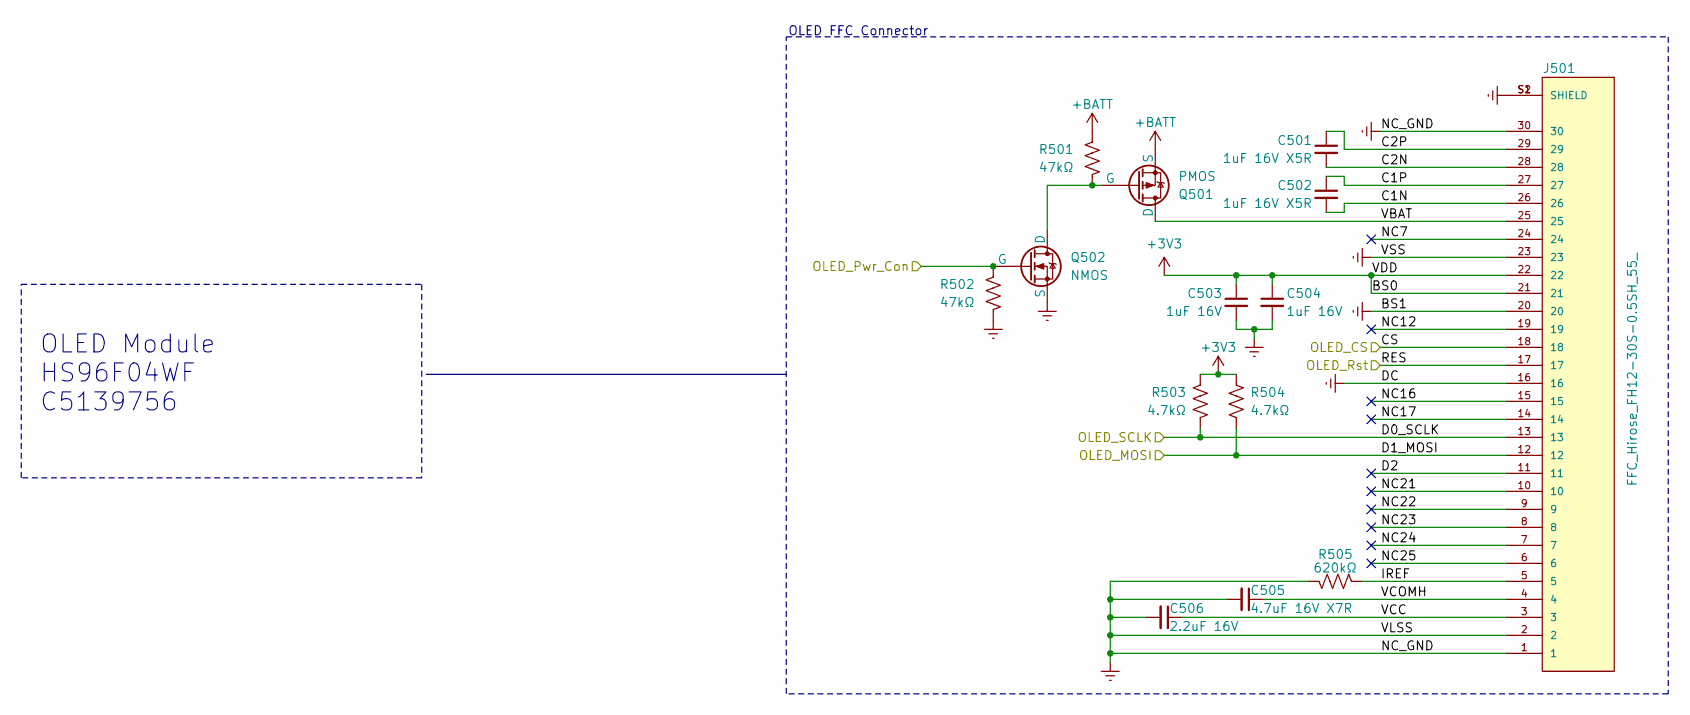
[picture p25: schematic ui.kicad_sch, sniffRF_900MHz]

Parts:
C501, C502: 1uF 16V X5R; C_0402_1005Metric_Pad0.74x0.62mm_HandSolder; MPN CC0402KRX5R7BB105; LCSC PN C325464
C503, C504: 1uF 16V; C_0402_1005Metric_Pad0.74x0.62mm_HandSolder; MPN CC0402KRX5R7BB105; LCSC PN C325464
C505: 4.7uF 16V X7R; C_0805_2012Metric_Pad1.18x1.45mm_HandSolder; MPN CC0805KKX7R7BB475; LCSC PN C277499
C506: 2.2uF 16V; C_0603_1608Metric_Pad1.08x0.95mm_HandSolder; MPN CL10A225KO8NNNC; LCSC PN C23630
J501: FFC_Hirose_FH12-30S-0.5SH_55_; FFC_Hirose_FH12-30S-0.5SH_55__HIROSE_FH12-30S-0.5SH_55_; MPN FH12-30S-0.5SH(55); LCSC PN C506793
Q501: PMOS; SOT-23_Handsoldering; MPN FDN338P; LCSC PN C24855
Q502: NMOS; SOT-23_Handsoldering; MPN FDN335N; LCSC PN C241804
R501, R502: 47kΩ; R_0603_1608Metric_Pad0.98x0.95mm_HandSolder; MPN 0603WAF4702T5E; LCSC PN C25819
R503, R504: 4.7kΩ; R_0805_2012Metric; MPN 0805W8F4701T5E; LCSC PN C17673
R505: 620kΩ; R_0402_1005Metric_Pad0.72x0.64mm_HandSolder; MPN RC0402FR-07620KL; LCSC PN C137952

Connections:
+3V3: C503.1, C504.1, J501.21, J501.22, R503.1, R504.1; also elsewhere on the board
+BATT: Q501.3 (S), R501.1; also elsewhere on the board
/MCU/OLED_Pwr_Con: Q502.2 (G), R502.1; also elsewhere on the board
/UI/C1N: C502.2, J501.26
/UI/C1P: C502.1, J501.27
/UI/C2N: C501.2, J501.28
/UI/C2P: C501.1, J501.29
/UI/CS: J501.18; also elsewhere on the board
/UI/D0_SCLK: J501.13, R503.2; also elsewhere on the board
/UI/D1_MOSI: J501.12, R504.2; also elsewhere on the board
/UI/D2: J501.11
/UI/IREF: J501.5, R505.1
/UI/NC7: J501.24
/UI/NC12: J501.19
/UI/NC16: J501.15
/UI/NC17: J501.14
/UI/NC21: J501.10
/UI/NC22: J501.9
/UI/NC23: J501.8
/UI/NC24: J501.7
/UI/NC25: J501.6
/UI/RES: J501.17; also elsewhere on the board
/UI/VBAT: J501.25, Q501.1 (D)
/UI/VCC: C506.1, J501.3
/UI/VCOMH: C505.1, J501.4
GNDREF: C503.2, C504.2, C505.2, C506.2, J501.1, J501.2, J501.16, J501.20, J501.23, J501.30, J501.S1 (SHIELD), J501.S2 (SHIELD), Q502.3 (S), R502.2, R505.2; also elsewhere on the board
unnamed: Q501.2 (G), Q502.1 (D), R501.2

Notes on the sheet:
OLED Module HS96F04WF C5139756
OLED FFC Connector

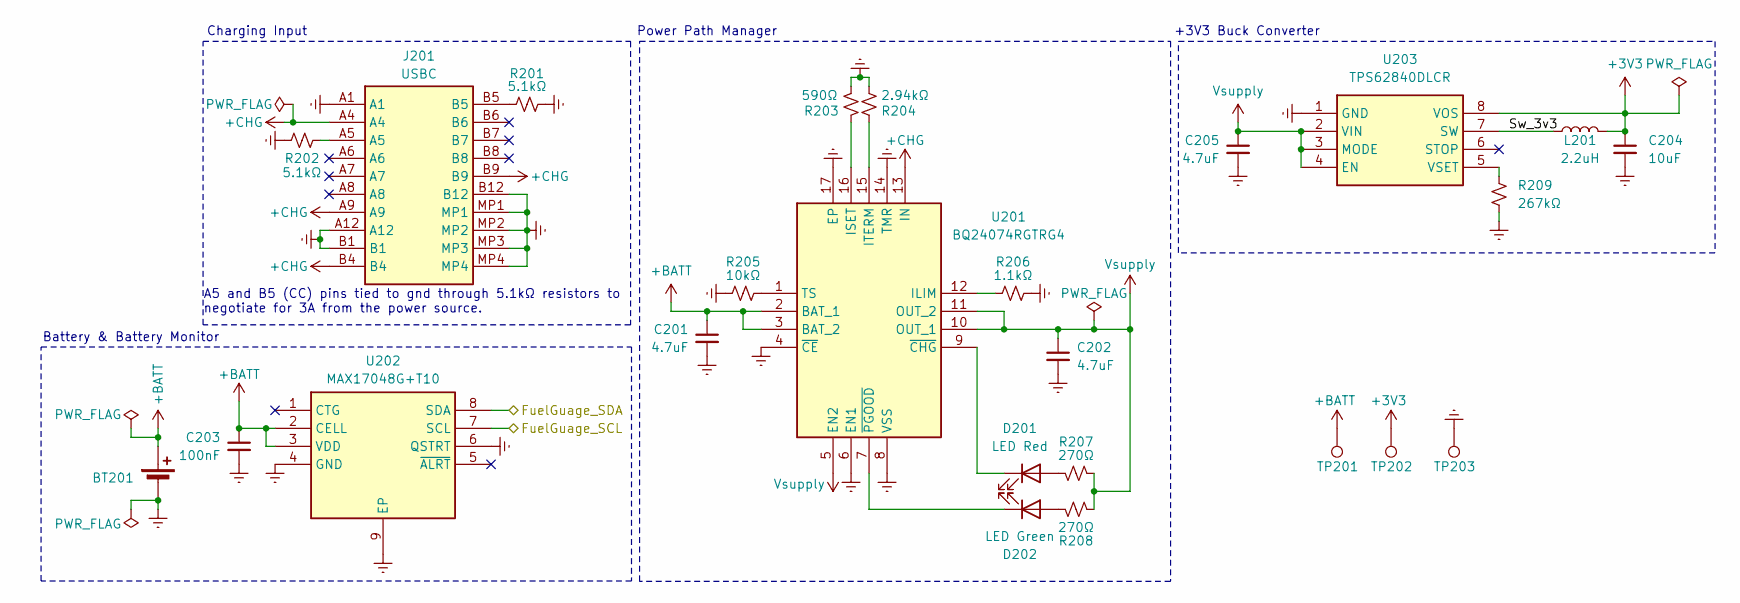
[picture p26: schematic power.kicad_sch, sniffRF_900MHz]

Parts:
BT201: 18650_Cell; BatteryHolder_Keystone_1043P; MPN 1043P; LCSC PN C3029535
C201, C202, C205: 4.7uF; C_0402_1005Metric_Pad0.74x0.62mm_HandSolder; MPN CL05A475MP5NRNC; LCSC PN C23733
C203: 100nF; C_0402_1005Metric_Pad0.74x0.62mm_HandSolder; MPN CL05B104KO5NNNC; LCSC PN C1525
C204: 10uF; C_0402_1005Metric_Pad0.74x0.62mm_HandSolder; MPN CL05A106MQ5NUNC; LCSC PN C15525
D201: LED Red; LED_Dialight_5973308207F; MPN 5973008207F; LCSC PN C6095189
D202: LED Green; LED_Dialight_5973308207F; MPN 5973308207F; LCSC PN C7188877
J201: USBC; Connector_GCT_USB4110GFA; MPN USB4110-GF-A; LCSC PN C5143397
L201: 2.2uH; Inductor_Murata_1286ASH1R0MP2; MPN DFE201612E-2R2M=P2; LCSC PN C337893
R201, R202: 5.1kΩ; R_0603_1608Metric_Pad0.98x0.95mm_HandSolder; MPN 0603WAF5101T5E; LCSC PN C23186
R203: 590Ω; R_0603_1608Metric_Pad0.98x0.95mm_HandSolder; MPN AC0603FR-07590RL; LCSC PN C227973
R204: 2.94kΩ; R_0402_1005Metric_Pad0.72x0.64mm_HandSolder; MPN RT0402BRD072K94L; LCSC PN C852709
R205: 10kΩ; R_0402_1005Metric_Pad0.72x0.64mm_HandSolder; MPN 0402WGJ0103TCE; LCSC PN C25531
R206: 1.1kΩ; R_0603_1608Metric_Pad0.98x0.95mm_HandSolder; MPN RT0603BRE071K1L; LCSC PN C705821
R207, R208: 270Ω; R_0805_2012Metric_Pad1.20x1.40mm_HandSolder; MPN 0805W8F2700T5E; LCSC PN C17590
R209: 267kΩ; R_1206_3216Metric_Pad1.30x1.75mm_HandSolder; MPN RT1206BRD07267KL; LCSC PN C870591
TP201, TP202, TP203: +Batt; TestPoint_Pad_D1.0mm
U201: BQ24074RGTRG4; PowerPath_TI_QFN50P300X300X100-17N-D; Manufacturer_Part_Number BQ24074RGTRG4; Mouser Part Number 595-BQ24074RGTRG4
U202: MAX17048G+T10; FuelGauge_AD_SON50P200X200X80-9N-D; MPN MAX17048G+T10; LCSC PN C2682616
U203: TPS62840DLCR; Buck_TI_SON50P150X200X100-8N-D; MPN TPS62840DLCR; LCSC PN C2071859

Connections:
+3V3: C204.1, L201.2, TP202.1, U203.8 (VOS); also elsewhere on the board
+BATT: BT201.2 (+), C201.1, C203.1, TP201.1, U201.2 (BAT_1), U201.3 (BAT_2), U202.2 (CELL), U202.3 (VDD); also elsewhere on the board
+CHG: J201.A4, J201.A9, J201.B4, J201.B9, U201.13 (IN)
/MCU/I2C1_SCL: U202.7 (SCL); also elsewhere on the board
/MCU/I2C1_SDA: U202.8 (SDA); also elsewhere on the board
/Power/Sw_3v3: L201.1, U203.7 (SW)
GNDREF: BT201.1 (-), C201.2, C202.2, C203.2, C204.2, C205.2, J201.A1, J201.A12, J201.B1, J201.B12, J201.MP1, J201.MP2, J201.MP3, J201.MP4, R201.1, R202.1, R203.1, R204.1, R205.1, R206.2, R209.2, TP203.1, U201.4 (~CE), U201.6 (EN1), U201.8 (VSS), U201.14 (TMR), U201.17 (EP), U202.4 (GND), U202.6 (QSTRT), U202.9 (EP), U203.1 (GND); also elsewhere on the board
unnamed: D201.2 (A), R207.2
unnamed: D201.1 (K), U201.9 (~CHG)
unnamed: D202.2 (A), R208.1
unnamed: D202.1 (K), U201.7 (~PGOOD)
unnamed: J201.A5, R202.2
unnamed: J201.B5, R201.2
unnamed: R206.1, U201.12 (ILIM)
unnamed: R203.2, U201.16 (ISET)
unnamed: R204.2, U201.15 (ITERM)
unnamed: R205.2, U201.1 (TS)
unnamed: R209.1, U203.5 (VSET)
Vsupply: C202.1, C205.1, R207.1, R208.2, U201.5 (EN2), U201.10 (OUT_1), U201.11 (OUT_2), U203.2 (VIN), U203.3 (MODE), U203.4 (EN)

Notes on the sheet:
A5 and B5 (CC) pins tied to gnd through 5.1kΩ resistors to negotiate for 3A from the power source.
Charging Input
Battery & Battery Monitor
+3V3 Buck Converter
Power Path Manager

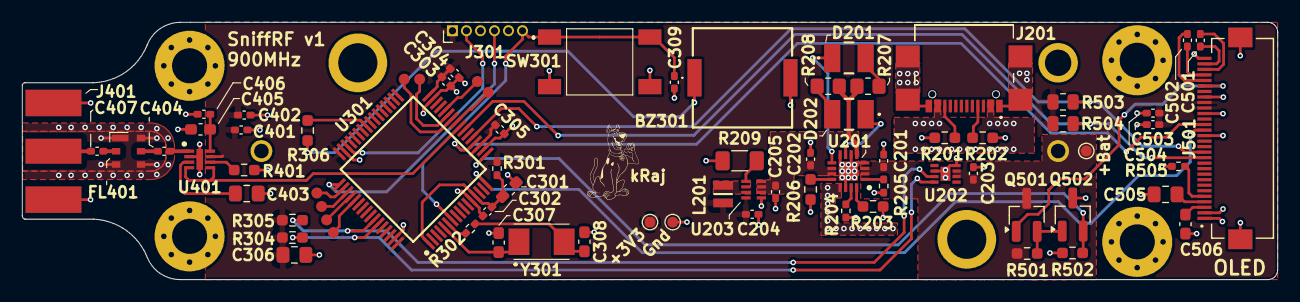
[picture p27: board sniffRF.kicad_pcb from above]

Board: 4 copper layers, 113.8 x 23.3 mm, 81 parts (1 on the bottom side), 58 nets.

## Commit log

2025-12-24 Updated readme and file structure, bug fixes and prep for manuf
    [SniffRF_BOM.xlsx, bom.csv, designators.csv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]
2025-12-27 Added pdf sch and layout, updated file struc
    [sniffRF.kicad_pcb]
2026-03-04 Updated readme and media
    [SniffRF_BOM.xlsx, antenna_900mhz.stl, bom.csv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]
